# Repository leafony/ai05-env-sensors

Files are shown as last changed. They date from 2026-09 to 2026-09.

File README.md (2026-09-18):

# AI05 Env Sensors

温湿度・気圧・3軸加速度を測定する Leafony リーフの KiCad プロジェクトです。

## 構成部品

| 部品 | メーカー | 機能 |
| --- | --- | --- |
| SHT40-AD1B-R2 | Sensirion | 温湿度 |
| SGP40-D-R4 | Sensirion | VOC ガス（選択実装） |
| BME280 / BME680 | Bosch Sensortec | 温湿度・気圧 / 温湿度・気圧・ガス（選択実装） |
| LIS2DW12TR | STMicroelectronics | 3軸加速度 |
| SM04B-SRSS-TB | JST | Qwiic、4極、1 mm ピッチ、横出し |

全センサーは Leafony Bus の **3.3 V・I²C** に接続します。基板は **23 × 20 mm、4層、板厚 0.8 mm** です。

SGP40は標準構成でDNPとします。

BME280 と BME680 は専用フットプリントをそれぞれ設け、**片方だけを実装**します。標準構成は BME280（U3、C5、C6）を実装し、BME680（U4、C7、C8）を DNP とします。BME680 構成ではこの実装・未実装を入れ替えます。

| センサー | I²C アドレス |
| --- | --- |
| SHT40 | `0x44` |
| SGP40 | `0x59` |
| BME280 / BME680 | `0x76` |
| LIS2DW12 | `0x19` |

LIS2DW12 の割り込み端子はD3に接続されます。I2C通信速度の上限は 400 kHz です。

SDA/SCL のプルアップはAP03 STM32リーフに搭載されているためDNPとします。既存 AI01 4-Sensors とは加速度センサーのアドレスと割り込みピンが重複するため、同じバスに同時接続しないでください。

## ライセンス

MIT

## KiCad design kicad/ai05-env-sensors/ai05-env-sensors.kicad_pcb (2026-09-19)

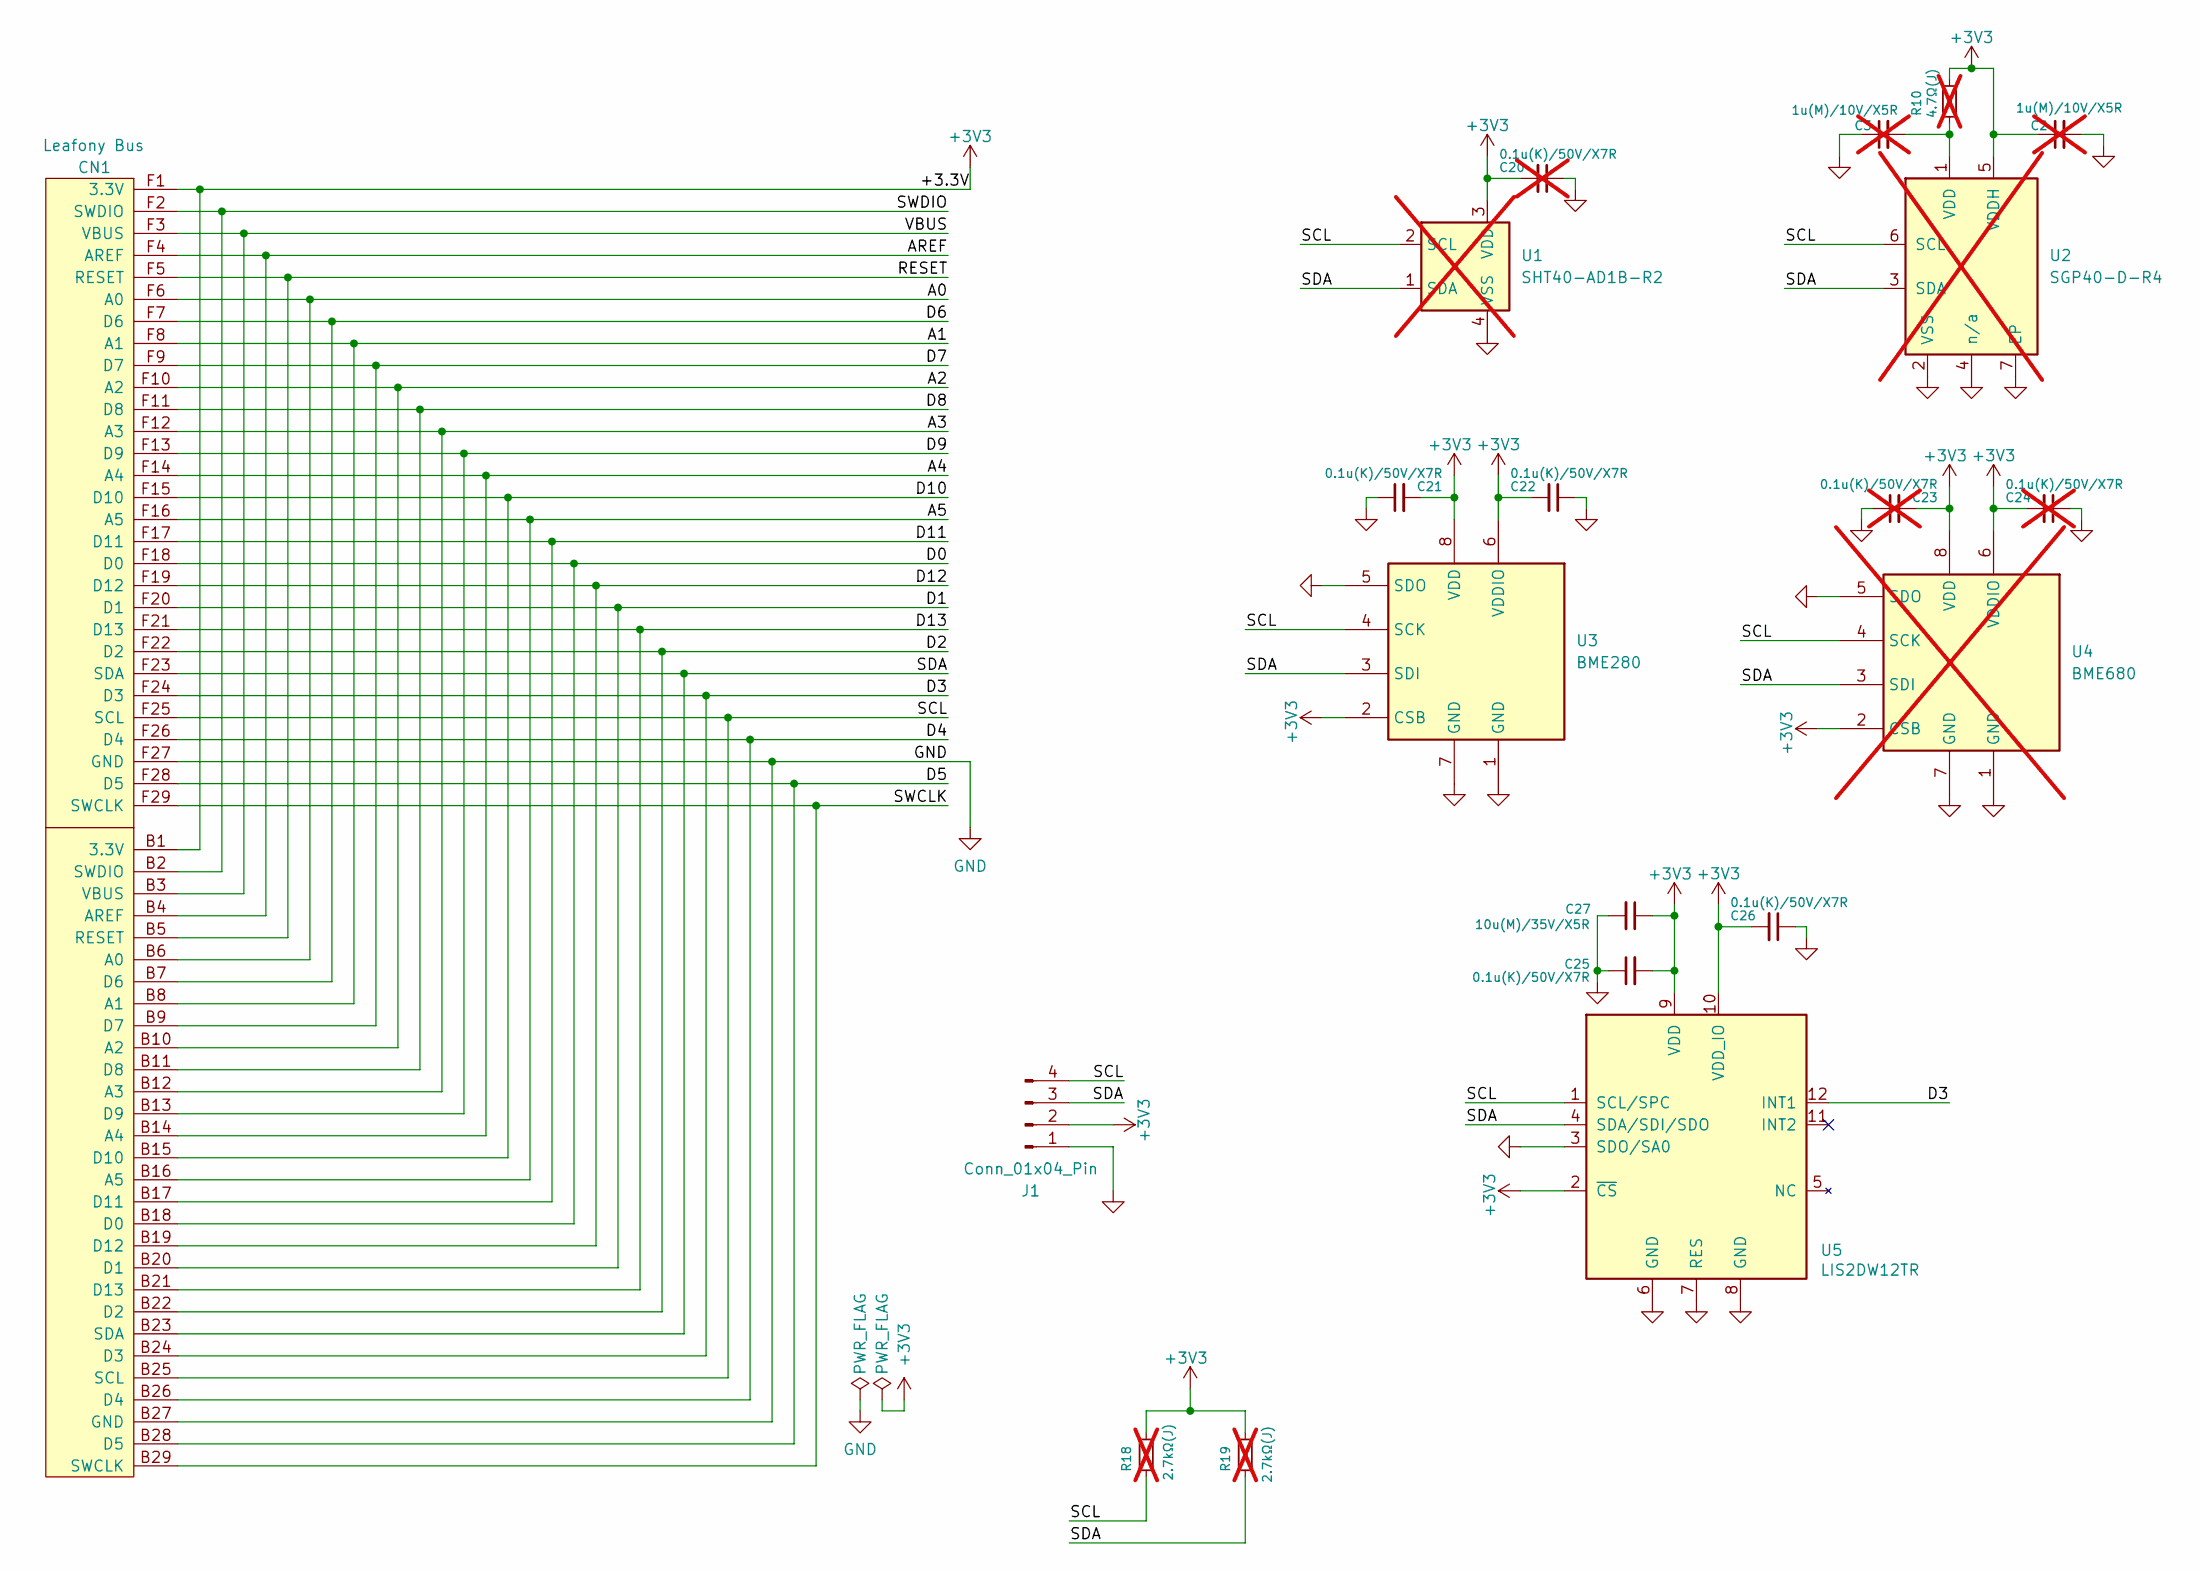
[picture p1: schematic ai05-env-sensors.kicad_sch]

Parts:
C2, C3: 1u(M)/10V/X5R; C_0402_1005Metric; MPN CC0402MRX5R6BB105; Digi-Key Product Number 311-1732-1-ND; not fitted
C20, C23, C24: 0.1u(K)/50V/X7R; C_0402_1005Metric; MPN CC0402KRX7R9BB104; not fitted
C21, C22, C25, C26: 0.1u(K)/50V/X7R; C_0402_1005Metric; MPN CC0402KRX7R9BB104
C27: 10u(M)/35V/X5R; C_0603_1608Metric; MPN GRM188R6YA106MA73J; Digi-Key Product Number 490-GRM188R6YA106MA73JCT-ND
CN1: Leafony Bus; CN_F29_B29
J1: Conn_01x04_Pin; PinHeader_1x04_P2.54mm_Horizontal
R10: 4.7Ω(J); R_0402_1005Metric; MPN RC0402JR-074R7L; Digi-Key Product Number 311-4.7JRCT-ND; not fitted
R18, R19: 2.7kΩ(J); R_0402_1005Metric; MPN RC0402JR-072K7L; Digi-Key Product Number 311-2.7KJRCT-ND; not fitted
U1: SHT40-AD1B-R2; Sensirion_DFN-4_1.5x1.5mm_P0.8mm_SHT4x_NoCentralPad; MPN SHT40-AD1B-R2; not fitted
U2: SGP40-D-R4; Sensirion_DFN-6-1EP_2.44x2.44mm_P0.8mm_SGP40; MPN SGP40-D-R4; not fitted
U3: BME280; Bosch_LGA-8_2.5x2.5mm_P0.65mm_ClockwisePinNumbering; MPN BME280
U4: BME680; Bosch_LGA-8_3x3mm_P0.8mm_ClockwisePinNumbering_Recommended; MPN BME680; not fitted
U5: LIS2DW12TR; LGA-12_2x2mm_P0.5mm; MPN LIS2DW12TR

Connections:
+3V3: C2.1, C20.2, C21.2, C22.2, C23.2, C24.2, C25.2, C26.2, C27.1, CN1.B1 (3.3V), CN1.F1 (3.3V), J1.2, R10.2, R18.1, R19.1, U1.3 (VDD), U2.5 (VDDH), U3.2 (CSB), U3.6 (VDDIO), U3.8 (VDD), U4.2 (CSB), U4.6 (VDDIO), U4.8 (VDD), U5.2 (~CS), U5.9 (VDD), U5.10 (VDD_IO)
/A0: CN1.B6 (A0), CN1.F6 (A0)
/A1: CN1.B8 (A1), CN1.F8 (A1)
/A2: CN1.B10 (A2), CN1.F10 (A2)
/A3: CN1.B12 (A3), CN1.F12 (A3)
/A4: CN1.B14 (A4), CN1.F14 (A4)
/A5: CN1.B16 (A5), CN1.F16 (A5)
/AREF: CN1.B4 (AREF), CN1.F4 (AREF)
/D0: CN1.B18 (D0), CN1.F18 (D0)
/D1: CN1.B20 (D1), CN1.F20 (D1)
/D2: CN1.B22 (D2), CN1.F22 (D2)
/D3: CN1.B24 (D3), CN1.F24 (D3), U5.12 (INT1)
/D4: CN1.B26 (D4), CN1.F26 (D4)
/D5: CN1.B28 (D5), CN1.F28 (D5)
/D6: CN1.B7 (D6), CN1.F7 (D6)
/D7: CN1.B9 (D7), CN1.F9 (D7)
/D8: CN1.B11 (D8), CN1.F11 (D8)
/D9: CN1.B13 (D9), CN1.F13 (D9)
/D10: CN1.B15 (D10), CN1.F15 (D10)
/D11: CN1.B17 (D11), CN1.F17 (D11)
/D12: CN1.B19 (D12), CN1.F19 (D12)
/D13: CN1.B21 (D13), CN1.F21 (D13)
/RESET: CN1.B5 (RESET), CN1.F5 (RESET)
/SCL: CN1.B25 (SCL), CN1.F25 (SCL), J1.4, R18.2, U1.2 (SCL), U2.6 (SCL), U3.4 (SCK), U4.4 (SCK), U5.1 (SCL/SPC)
/SDA: CN1.B23 (SDA), CN1.F23 (SDA), J1.3, R19.2, U1.1 (SDA), U2.3 (SDA), U3.3 (SDI), U4.3 (SDI), U5.4 (SDA/SDI/SDO)
/SWCLK: CN1.B29 (SWCLK), CN1.F29 (SWCLK)
/SWDIO: CN1.B2 (SWDIO), CN1.F2 (SWDIO)
/VBUS: CN1.B3 (VBUS), CN1.F3 (VBUS)
GND: C2.2, C3.1, C20.1, C21.1, C22.1, C23.1, C24.1, C25.1, C26.1, C27.2, CN1.B27 (GND), CN1.F27 (GND), J1.1, U1.4 (VSS), U2.2 (VSS), U2.4 (n/a), U2.7 (EP), U3.1 (GND), U3.5 (SDO), U3.7 (GND), U4.1 (GND), U4.5 (SDO), U4.7 (GND), U5.3 (SDO/SA0), U5.6 (GND), U5.7 (RES), U5.8 (GND)
unnamed: C3.2, R10.1, U2.1 (VDD)

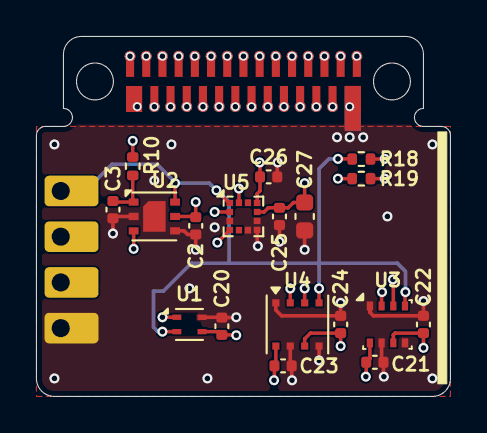
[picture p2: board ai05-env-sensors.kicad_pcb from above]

Board: 4 copper layers, 23.0 x 20.0 mm, 20 parts (0 on the bottom side), 30 nets.

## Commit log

2026-09-18 KiCadプロジェクトを作成
    [ai05-env-sensors.kicad_pcb, ai05-env-sensors.kicad_sch]
2026-09-18 README更新
2026-09-18 Add new footprints for various sensors and connectors
    [ai05-env-sensors.kicad_pcb, ai05-env-sensors.kicad_sch]
2026-09-19 レイアウト完成
    [ai05-env-sensors.kicad_pcb, ai05-env-sensors.kicad_sch]
2026-09-19 面付・ガーバー出力
    [ai05-env-sensors-B_Cu.gbl, ai05-env-sensors-B_Mask.gbs, ai05-env-sensors-B_Paste.gbp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]
2026-11-03 AP03向け環境センサー読み出しサンプルを追加
2026-11-03 PlatformIOサンプルを個別フォルダに整理
2026-11-03 加速度センサーの動き検出割り込みサンプルを追加 (#3)
2026-11-03 衝撃検出後のFIFO記録サンプルと波形ビューアを追加 (#4)
2026-11-13 回路図・レイアウトPDFの自動生成を追加 (#5)
    * 回路図・レイアウトPDFを自動生成するCIを追加
    * CIで生成した回路図・レイアウトPDFを追加
